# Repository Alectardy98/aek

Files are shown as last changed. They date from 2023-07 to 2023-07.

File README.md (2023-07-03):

# djaek 
    A Drop In Replacement PCB the AEK and AEKII

AEKII Top
AEKII Bottom

All Supported Layouts can be seen [here](http://www.keyboard-layout-editor.com/#/gists/c7bd3d0e6c43f816d1fdc86e6fad2cfd)

USB/QMK atmega32u4 pcb for The Apple AEK and AEK II

- The firmware can be found in the firmware folder
- All files for production though JLCPCB can be found in the JLCPCB folder
- This PCB supports an ATMEGA32u4-AU/ Atmega32u4-MU and works qmk/vial
- All Layouts support both MX and alps Switches
- Additional Files including plate files can be found in the meta folder. Other plate files have not been made at this time
- Lock Lights ARE REPLACED With WS2812B LED, and will not toggle on lock activation, and instead will act as underglow LEDS
  - Recomendations for [SMT](https://www.lcsc.com/product-detail/Light-Emitting-Diodes-LED_Worldsemi-WS2812B-B-W_C2761795.html) and [THT](https://soldered.com/product/rgb-led-diode-ws2812b-f8-tht/) parts

Released without warranty, use at your own risk.  
This PCB was created by dj156 and modified by Alectardy98

---
| Authors | 

dj156

| Modified |

Alectardy98

---

Shield: [][cc-by-sa]

This work is licensed under a
[Creative Commons Attribution-ShareAlike 4.0 International License][cc-by-sa].

[][cc-by-sa]

[cc-by-sa]: http://creativecommons.org/licenses/by-sa/4.0/
[cc-by-sa-image]: https://licensebuttons.net/l/by-sa/4.0/88x31.png
[cc-by-sa-shield]: https://img.shields.io/badge/License-CC%20BY--SA%204.0-lightgrey.svg

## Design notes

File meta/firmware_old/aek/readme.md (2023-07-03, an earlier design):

# aek

aek

*A short description of the keyboard/project*

* Keyboard Maintainer: [djvs](https://github.com/yourusername)
* Hardware Supported: *The PCBs, controllers supported*
* Hardware Availability: *Links to where you can find this hardware*

Make example for this keyboard (after setting up your build environment):

    make aek:default

Flashing example for this keyboard:

    make aek:default:flash

See the [build environment setup](https://docs.qmk.fm/#/getting_started_build_tools) and the [make instructions](https://docs.qmk.fm/#/getting_started_make_guide) for more information. Brand new to QMK? Start with our [Complete Newbs Guide](https://docs.qmk.fm/#/newbs).

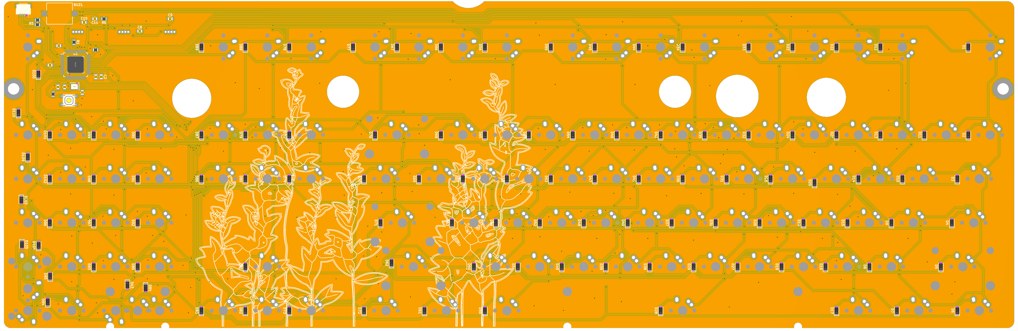
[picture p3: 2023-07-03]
meta/AEKII Bottom.png

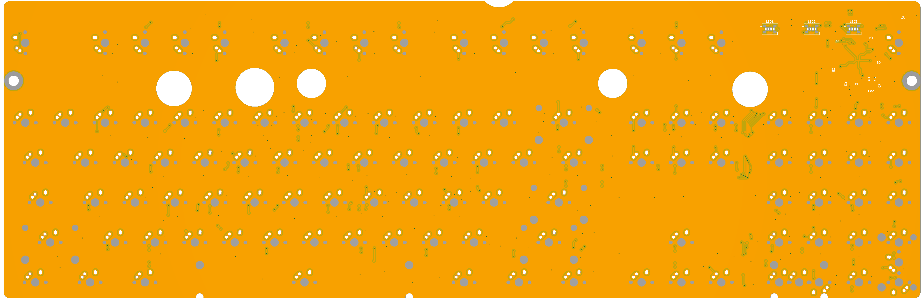
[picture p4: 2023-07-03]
meta/AEKII Top.png

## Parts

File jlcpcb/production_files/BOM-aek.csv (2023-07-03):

Comment | Designator | Footprint | LCSC
ATmega32U4-MU | U1 | atmega32u4-mu-and-au | C112161
D_Small | D1,D10,D100,D101,D102,D103,D104,D105,D109,D11,D110,D12,D13,D14,D15,D16,D17,D18,D19,D2,D20,D21,D22,D23,D24,D25,D26,D27,D28,D29,D3,D30,D31,D32,D33,D34,D35,D36,D37,D38,D39,D4,D40,D41,D42,D43,D44,D45,D46,D47,D48,D49,D5,D50,D51,D52,D53,D54,D55,D56,D57,D58,D59,D6,D60,D61,D62,D63,D64,D65,D66,D67,D68,D69,D7,D70,D71,D72,D73,D74,D75,D76,D77,D78,D79,D8,D80,D81,D82,D83,D84,D85,D86,D87,D88,D89,D9,D90,D91,D92,D93,D94,D95,D96,D97,D98,D99 | D_SOD-123 | C2099
WS2812B | LED1,LED2,LED3 | WS2812BDual | C2761795
SW_Push | SW1 | SKQG-1155865 | C318884
MountingHole_Pad | H2 | MountingHole_2.7mm_M2.5_Pad
MX-NoLED | SW_0 | MX-1U-NoLED
MX-NoLED | SW_1 | MX-1U-NoLED
MX-NoLED | SW_2 | MX-1U-NoLED
MX-NoLED | SW_3 | MX-1U-NoLED
MX-NoLED | SW_6 | MX-1U-NoLED
MX-NoLED | SW_7 | MX-1U-NoLED
MX-NoLED | SW_8 | MX-1U-NoLED
MX-NoLED | SW_9 | MX-1U-NoLED
MX-NoLED | SW_A1 | MX-1U-NoLED
MX-NoLED | SW_APOS1 | MX-1U-NoLED
MX-NoLED | SW_B1 | MX-1U-NoLED
MX-NoLED | SW_BACKSP1 | MX-2U-NoLED
MX-NoLED | SW_BKSLS1 | MX-1.5U-NoLED
MX-NoLED | SW_C1 | MX-1U-NoLED
MX-NoLED | SW_CAP1 | MX-1.75U-NoLED
MX-NoLED | SW_COLON1 | MX-1U-NoLED
MX-NoLED | SW_COMMA1 | MX-1U-NoLED
MX-NoLED | SW_D1 | MX-1U-NoLED
MX-NoLED | SW_DEL1 | MX-1U-NoLED
MX-NoLED | SW_DOWN1 | MX-1U-NoLED
MX-NoLED | SW_E1 | MX-1U-NoLED
MX-NoLED | SW_END1 | MX-1U-NoLED
MX-NoLED | SW_ENTER1 | MX-2.25U-NoLED
MX-NoLED | SW_EQ1 | MX-1U-NoLED
MX-NoLED | SW_ESC1 | MX-1U-NoLED
MX-NoLED | SW_F1 | MX-1U-NoLED
MX-NoLED | SW_F2 | MX-1U-NoLED
MX-NoLED | SW_F3 | MX-1U-NoLED
MX-NoLED | SW_F4 | MX-1U-NoLED
MX-NoLED | SW_F5 | MX-1U-NoLED
MX-NoLED | SW_F6 | MX-1U-NoLED
MX-NoLED | SW_F7 | MX-1U-NoLED
MX-NoLED | SW_F8 | MX-1U-NoLED
MX-NoLED | SW_F9 | MX-1U-NoLED
MX-NoLED | SW_F10 | MX-1U-NoLED
MX-NoLED | SW_F11 | MX-1U-NoLED
MX-NoLED | SW_F12 | MX-1U-NoLED
MX-NoLED | SW_F13 | MX-1U-NoLED
MX-NoLED | SW_G1 | MX-1U-NoLED
MX-NoLED | SW_H1 | MX-1U-NoLED
MX-NoLED | SW_HOME1 | MX-1U-NoLED
MX-NoLED | SW_I1 | MX-1U-NoLED
MX-NoLED | SW_INS1 | MX-1U-NoLED
MX-NoLED | SW_J1 | MX-1U-NoLED
MX-NoLED | SW_K1 | MX-1U-NoLED
MX-NoLED | SW_KP0 | MX-2U-ReversedStabilizers-NoLED
MX-NoLED | SW_KP1 | MX-1U-NoLED
MX-NoLED | SW_KP2 | MX-1U-NoLED
MX-NoLED | SW_KP3 | MX-1U-NoLED
MX-NoLED | SW_KP4 | MX-1U-NoLED
MX-NoLED | SW_KP5 | MX-1U-NoLED
MX-NoLED | SW_KP6 | MX-1U-NoLED
MX-NoLED | SW_KP7 | MX-1U-NoLED
MX-NoLED | SW_KP8 | MX-1U-NoLED
MX-NoLED | SW_KP9 | MX-1U-NoLED
MX-NoLED | SW_KPASTR1 | MX-1U-NoLED
MX-NoLED | SW_KPENTER1 | MX-2U-ReversedStabilizers-NoLED
MX-NoLED | SW_KPEQ1 | MX-1U-NoLED
MX-NoLED | SW_KPMINUS1 | MX-1U-NoLED
MX-NoLED | SW_KPPER1 | MX-1U-NoLED
MX-NoLED | SW_KPPLUS1 | MX-1U-NoLED
MX-NoLED | SW_L1 | MX-1U-NoLED
MX-NoLED | SW_LALT1 | MX-1.5U-NoLED
MX-NoLED | SW_LBRAC1 | MX-1U-NoLED
MX-NoLED | SW_LCTR1 | MX-1.5U-NoLED
MX-NoLED | SW_LEFT1 | MX-1U-NoLED
MX-NoLED | SW_LMOD1 | MX-1.25U-NoLED
MX-NoLED | SW_LSH1 | MX-2.25U-NoLED
MX-NoLED | SW_M1 | MX-1U-NoLED
MX-NoLED | SW_MINUS1 | MX-1U-NoLED
MX-NoLED | SW_N1 | MX-1U-NoLED
MX-NoLED | SW_O1 | MX-1U-NoLED
MX-NoLED | SW_P1 | MX-1U-NoLED
MX-NoLED | SW_PAUSE1 | MX-1U-NoLED
MX-NoLED | SW_PERIOD1 | MX-1U-NoLED
MX-NoLED | SW_PGDN1 | MX-1U-NoLED
MX-NoLED | SW_PGUP1 | MX-1U-NoLED
MX-NoLED | SW_POW1 | MX-1U-NoLED
MX-NoLED | SW_PRSC1 | MX-1U-NoLED
MX-NoLED | SW_Q1 | MX-1U-NoLED
MX-NoLED | SW_R1 | MX-1U-NoLED
MX-NoLED | SW_RALT1 | MX-1.5U-NoLED
MX-NoLED | SW_RBRAC1 | MX-1U-NoLED
MX-NoLED | SW_RCTR1 | MX-1.5U-NoLED
MX-NoLED | SW_RIGHT1 | MX-1U-NoLED
MX-NoLED | SW_RMOD1 | MX-1.25U-NoLED
MX-NoLED | SW_RSH1 | MX-2.75U-NoLED
MX-NoLED | SW_S1 | MX-1U-NoLED
MX-NoLED | SW_SCLK1 | MX-1U-NoLED
MX-NoLED | SW_SLASH1 | MX-1U-NoLED
MX-NoLED | SW_SPACE1 | MX-6.5U-ReversedStabilizers-NoLED
MX-NoLED | SW_T1 | MX-1U-NoLED
MX-NoLED | SW_TAB1 | MX-1.5U-NoLED
MX-NoLED | SW_TICK1 | MX-1U-NoLED
MX-NoLED | SW_U1 | MX-1U-NoLED
MX-NoLED | SW_UP1 | MX-1U-NoLED
MX-NoLED | SW_V1 | MX-1U-NoLED
MX-NoLED | SW_W1 | MX-1U-NoLED
MX-NoLED | SW_X1 | MX-1U-NoLED
MX-NoLED | SW_Y1 | MX-1U-NoLED
MX-NoLED | SW_Z1 | MX-1U-NoLED
MountingHole_Pad | H1 | MountingHole_2.7mm_M2.5_Pad
MX-NoLED | SW_4 | MX-1U-NoLED
MX-NoLED | SW_5 | MX-1U-NoLED
MX-NoLED | SW_NUMLK1 | MX-1U-NoLED
MX-NoLED | SW_KP0X1 | MX-1U-NoLED
MX-NoLED | SW_KPENTERALT1 | MX-1U-NoLED
MX-NoLED | SW_KPSLASH1 | MX-1U-NoLED
MX-NoLED | SW_KP0ALT1 | MX-1U-NoLED
MX-NoLED | SW_KPENTERX1 | MX-1U-NoLED
0.1uF | C8 | C_0805_2012Metric
0.1uF | C9 | C_0805_2012Metric
0.1uF | C10 | C_0805_2012Metric
330 | R1 | R_0805_2012Metric
0.1uF | C1 | C_0805_2012Metric
0.1uF | C2 | C_0805_2012Metric
0.1uF | C5 | C_0805_2012Metric
1uF | C6 | C_0805_2012Metric
10uF | C7 | C_0805_2012Metric
Conn_01x04_MountingPin | J1 | JST_SH_SM04B-SRSS-TB_1x04-1MP_P1.00mm_Horizontal
10k | R3 | R_0805_2012Metric
10k | R4 | R_0805_2012Metric
16MHz | Y1 | Crystal_SMD_3225-4Pin_3.2x2.5mm
22pF | C3 | C_0805_2012Metric
22pF | C4 | C_0805_2012Metric
0.1uF | C11 | C_0805_2012Metric
22 | R5 | R_0805_2012Metric
22 | R2 | R_0805_2012Metric
22 | R6 | R_0805_2012Metric
Buzzer | BUZ1 | Buzzer_Mallory_AST1109MLTRQ

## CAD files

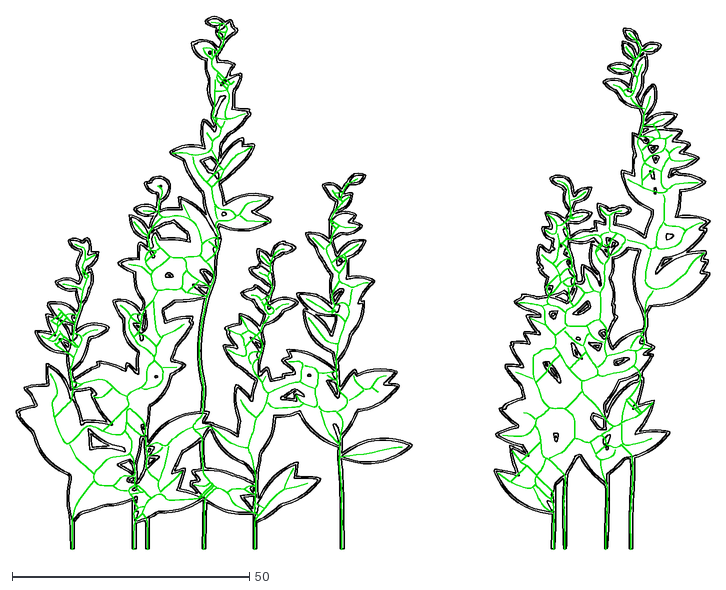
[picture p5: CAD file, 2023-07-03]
meta/art/drawing.dxf
146.1 x 112.3

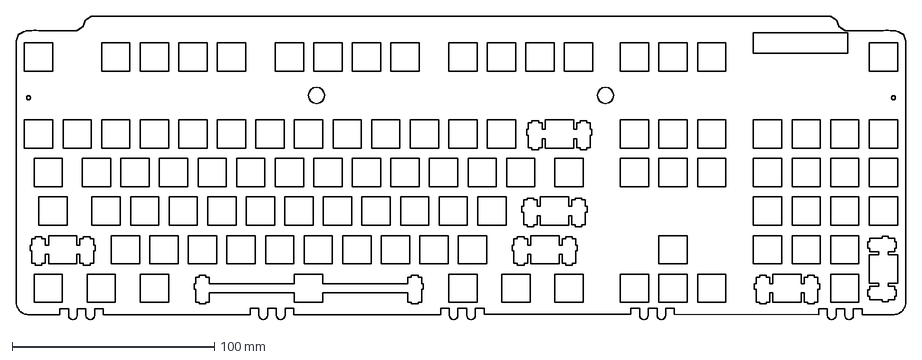
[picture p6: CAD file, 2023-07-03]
meta/mxplate.dxf
439.2 x 149.8 mm

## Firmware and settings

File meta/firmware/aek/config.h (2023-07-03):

/*
Copyright 2021 djvs

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
You should have received a copy of the GNU General Public License
along with this program.  If not, see <http://www.gnu.org/licenses/>.
*/

#pragma once

#include "config_common.h"

/* USB Device descriptor parameter */
#define VENDOR_ID    0x1209
#define PRODUCT_ID   0x9209
#define DEVICE_VER   0x0001
#define MANUFACTURER djvs
#define PRODUCT      AEK II

/* key matrix size */
#define MATRIX_ROWS 11
#define MATRIX_COLS 10

/*
 * Keyboard Matrix Assignments
 *
 * Change this to how you wired your keyboard
 * COLS: AVR pins used for columns, left to right
 * ROWS: AVR pins used for rows, top to bottom
 * DIODE_DIRECTION: COL2ROW = COL = Anode (+), ROW = Cathode (-, marked on diode)
 *                  ROW2COL = ROW = Anode (+), COL = Cathode (-, marked on diode)
 *
 */
#define MATRIX_ROW_PINS { D7, B3, B7, D1, D3, D4, D5, D2, D0, B2, B1 }
#define MATRIX_COL_PINS { F0, F1, F5, F6, F7, B6, B5, B4, D6, B0 }

/* COL2ROW, ROW2COL */
#define DIODE_DIRECTION COL2ROW

/*
 * Split Keyboard specific options, make sure you have 'SPLIT_KEYBOARD = yes' in your rules.mk, and define SOFT_SERIAL_PIN.
 */
// #define SOFT_SERIAL_PIN D0  // or D1, D2, D3, E6

//#define LED_NUM_LOCK_PIN B0
//#define LED_CAPS_LOCK_PIN B1
//#define LED_SCROLL_LOCK_PIN B2
//#define LED_COMPOSE_PIN B3
//#define LED_KANA_PIN B4

//#define BACKLIGHT_PIN F4
//#define BACKLIGHT_CAPS_LOCK
//#define BACKLIGHT_DRIVER = 
//#define BACKLIGHT_LEVELS 3
//#define BACKLIGHT_BREATHING

#define RGB_DI_PIN F4
#ifdef RGB_DI_PIN
#    define RGBLED_NUM 3
#    define RGBLIGHT_DEFAULT_MODE (RGBLIGHT_MODE_RAINBOW_SWIRL)

#    define RGBLIGHT_DEFAULT_HUE 64
//#    define RGBLIGHT_DEFAULT_SAT 255
#    define RGBLIGHT_DEFAULT_VAL 255
//#    define RGBLIGHT_HUE_STEP 8
//#    define RGBLIGHT_SAT_STEP 8
//#    define RGBLIGHT_VAL_STEP 8
//#    define RGBLIGHT_LIMIT_VAL 255 /* The maximum brightness level */
//#    define RGBLIGHT_SLEEP  /* If defined, the RGB lighting will be switched off when the host goes to sleep */
/*== all animations enable ==*/
#    define RGBLIGHT_ANIMATIONS
/*== or choose animations ==*/
//#    define RGBLIGHT_EFFECT_BREATHING
//#    define RGBLIGHT_EFFECT_RAINBOW_MOOD
//#    define RGBLIGHT_EFFECT_RAINBOW_SWIRL
//#    define RGBLIGHT_EFFECT_SNAKE
//
//#    define RGBLIGHT_EFFECT_KNIGHT
//#    define RGBLIGHT_EFFECT_CHRISTMAS
//#    define RGBLIGHT_EFFECT_STATIC_GRADIENT
//#    define RGBLIGHT_EFFECT_RGB_TEST
//#    define RGBLIGHT_EFFECT_ALTERNATING
/*== customize breathing effect ==*/
/*==== (DEFAULT) use fixed table instead of exp() and sin() ====*/
//#    define RGBLIGHT_BREATHE_TABLE_SIZE 256      // 256(default) or 128 or 64
/*==== use exp() and sin() ====*/
//#    define RGBLIGHT_EFFECT_BREATHE_CENTER 1.85  // 1 to 2.7
//#    define RGBLIGHT_EFFECT_BREATHE_MAX    255   // 0 to 255
#endif

/* Debounce reduces chatter (unintended double-presses) - set 0 if debouncing is not needed */
#define DEBOUNCE 5

/* define if matrix has ghost (lacks anti-ghosting diodes) */
//#define MATRIX_HAS_GHOST

/* Mechanical locking support. Use KC_LCAP, KC_LNUM or KC_LSCR instead in keymap */
#define LOCKING_SUPPORT_ENABLE
/* Locking resynchronize hack */
#define LOCKING_RESYNC_ENABLE

/* If defined, GRAVE_ESC will always act as ESC when CTRL is held.
 * This is useful for the Windows task manager shortcut (ctrl+shift+esc).
 */
//#define GRAVE_ESC_CTRL_OVERRIDE

/*
 * Force NKRO
 *
 * Force NKRO (nKey Rollover) to be enabled by default, regardless of the saved
 * state in the bootmagic EEPROM settings. (Note that NKRO must be enabled in the
 * makefile for this to work.)
 *
 * If forced on, NKRO can be disabled via magic key (default = LShift+RShift+N)
 * until the next keyboard reset.
 *
 * NKRO may prevent your keystrokes from being detected in the BIOS, but it is
 * fully operational during normal computer usage.
 *
 * For a less heavy-handed approach, enable NKRO via magic key (LShift+RShift+N)
 * or via bootmagic (hold SPACE+N while plugging in the keyboard). Once set by
 * bootmagic, NKRO mode will always be enabled until it is toggled again during a
 * power-up.
 *
 */
//#define FORCE_NKRO

/*
 * Feature disable options
 *  These options are also useful to firmware size reduction.
 */

/* disable debug print */
//#define NO_DEBUG

/* disable print */
//#define NO_PRINT

/* disable action features */
//#define NO_ACTION_LAYER
//#define NO_ACTION_TAPPING
//#define NO_ACTION_ONESHOT

/* disable these deprecated features by default */
//#define NO_ACTION_MACRO
//#define NO_ACTION_FUNCTION

/* Bootmagic Lite key configuration */
//#define BOOTMAGIC_LITE_ROW 0
//#define BOOTMAGIC_LITE_COLUMN 0

#define DYNAMIC_KEYMAP_LAYER_COUNT 2

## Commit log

2023-07-03 cleanup and add firmware
    [aek-B_Cu.gbr, aek-B_Mask.gbr, aek-B_Silkscreen.gbr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]
2023-07-03 add jlc
    [BOM-aek.csv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]
2023-07-03 push remove backups
    [BOM-aek.csv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]

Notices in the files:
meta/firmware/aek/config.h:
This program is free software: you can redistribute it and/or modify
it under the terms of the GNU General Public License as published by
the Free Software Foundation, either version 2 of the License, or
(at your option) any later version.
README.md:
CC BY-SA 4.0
